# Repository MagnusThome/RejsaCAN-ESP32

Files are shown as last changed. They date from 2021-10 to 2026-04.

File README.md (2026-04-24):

# RejsaCAN

RejsaCAN is a 3x5 centimetre small ESP32 or ESP32-S3 based board aimed at car use that I put together for my own use in my assorted crazy car projects. The board has an onboard CAN interface and can be powered directly from the car (5-24V). It also includes the option to auto shutdown so not to drain the car battery. This is especially important if you have it plugged in to a car OBD2 connector since these always supply constant 12V power to the connector, even when the car is parked and turned off.

There is no bespoke code for the board apart from pin definitions, it's just a piece of universal hardware, but by using easy to use open source Arduino libraries it can be made to interface not only to various CAN buses, Network/Wifi and Bluetooth but to numerous sensors and other peripherals using the ESP32's built in interfaces.

You can assemble your own board if you want, you find schematics, Gerber files and bill of materials in the <a href=Schematics>schematics folder</a>. I currently have a few extra boards so if you need one or more factory assembled boards you can always contact me at magnust@gmail.com.
  
### Nice review and get started guide at cnx-software  
  
https://www.cnx-software.com/2023/05/12/rejsacan-esp32-s3-can-bus-board-arduino-car-hacking/  
  
### Navigate  
  
- <a href=./>Main page (this page)</a>  
 
- <a href=Projects%20and%20ideas>Fun projects and ideas</a>  
 
- <a href=Schematics>Schematics</a>

- <a href=Code%20Examples>Code examples</a>
 
- <a href=Tips%20to%20setup%20IDE%20and%20get%20started>Links to some different CAN libraries and tips to get started</a>  
  
-  <a href=3dprint>Examples of 3D printable housings</a>  

-  <a href=Auxiliary%20boards>Some odd auxiliary boards I made to mount an OBD2 connector, display, thermal cam...</a>  

<hr>
  


## Pinout  
  
See complete pinout.h https://github.com/MagnusThome/RejsaCAN-ESP32/blob/main/Schematics/

S3 rear

## Schematics

click to get full schematics



## The board is based around an ESP32 or ESP32-S3 chip

The ESP32-S3 is a very nice and capable chip that supports a mind boggling range of different communication standards and hardware auxiliaries making it a very versatile "hub" for shuffling data between different systems.  

- SPI bus
- I2C bus
- BLE (Bluetooth 5)
- Wifi (both as AP or client)
- Networking, everything from simple http, mqtt, ajax, ntp to running a full webserver on it with a user interface
- USB port (serial in/out and also OTG as virtual keyboard, wireless storage...)
- Analog input, PWM or analog output

## Examples

- Read CAN data and send back CAN packets to control the car (set to sport mode as default, lock doors when driving away, this is one of my current projects)
- CAN to BLE or network/Wifi bridge
- CAN interface for sniffing CAN bus with for example SavvyCAN
- Read I2C/SPI/analog sensor data and write to CAN bus for CAN bus based data loggers
- Publish live telemetric data on internet from Racechrono (I'm starting this project now)
- Drive alarm beeper or LED to show status of CAN data (like my small project Money Shift Saver and also low oil pressure warning)
- Drive high power peripherals using a driver board
- Translate CAN data between two CAN buses (like my small project Current Gear HUD here on github)

- I have already made a connector board to attach the RejsaCAN on the back of the commonly available small ILI9341 touch screen.

## Ideas for peripherals



- IR camera sensor arrays (MLX90xxx or AMG8833) to log tire, brake, drivetrain temperatures over BLE to Racechrono or CAN based loggers (like my project RejsaRubberTrac https://github.com/MagnusThome/RejsaRubberTrac)  
- Laser based TOF distance sensor to log suspension travel (I did this too with RejsaRubberTrac)  
- SPI or I2C based color displays to show CAN bus data like IC intake or oil temps or alarms  
- SPI or I2C based color displays to show live telemetric data fetched over BLE from Racechrono  
- A second CAN port  
- Driver board to drive high power items  
- Step motor drivers  
- Multiple input analog or digital boards  
   
## One of the 3D printed housings with OBD2 connector I've made


## Or just the board and screw terminals


# CAN interface

You can hook the board up straight to the car's OBD2 port or attach it directly to any CAN bus. You just need to connect the four wires. 12V power, ground, CAN high and low. There is of course a bus termination resistor on the board, it can be disabled if not needed by cutting a pcb trace and optionally mounting a pin header and jumper.

# Functionality

The idea was to make an as small as possible CAN + ESP32 board with as many cool and useful "good to have" functions as possible included. You know as well as I do that when tinkering around you suddenly get a new idea and need x or y :-D 

## Auto shutdown

When the engine is running and charging the car battery the incoming voltage used to power the board is a little bit higher than when the engine is stopped. This can be used to automate board shutdown so not to drain the car battery. As default the on board DC-DC power circuit will shutdown the whole board when the power voltage is below the "engine is running" threshold and boot up the board when it is above. But you can run the board in a number of other ways too, for example using ESP32 sleep mode, waking it and putting it to sleep depending on CAN traffic, voltage level from the car, delays and so on.

- An output (FORCE_ON GPIO17) can be pulled high to keep the board running even if the car voltage drops below the threshold (instead of disabling the auto shutdown fully on the pcb by shorting the "ALWAYS ON" bridge). The ESP32 can keep this pin high even during sleep.

- A digital input (SENSE_V_DIG GPIO08) monitors if the car voltage is above or below the "engine running" threshold. This can both be used to trigger waking the board from sleep or just as a simple check if the engine is charging the car battery or not.  

- The voltage from the car can be monitored using analog input (SENSE_V_ANA GPIO9) to check not only charging level but also battery discharge level when parked, health of charging, health of battery, detect large loads being switched on or off in the car and so on.

- The CAN data input (CAN_RX GPIO13) can also be used to trigger waking up the board from sleep as soon as CAN traffic is detected.

Either one can just let the board turn on and off with the auto shutdown hardware circuitry straight out of the box or you can run it in combination with software. For example, when the car voltage rises and the board boots you can pull FORCE_ON high to make sure the board keeps running even if there is a drop of voltage, for example due to red light start/stop functionality in the car or modern cars turning down battery charging even when driving. Then you just monitor either the threshold with SENSE_V_DIG or set your own thresholds using SENSE_V_ANA and then add your own timer delays or whatever. And of course, you can use CAN to check if the car is stopped in a multitude of ways, rpm, speed, gear...

### Fine tuning on/off voltage thresholds  

If your car has a more modern battery type than the old acid/led type or if it does the battery charging slightly different you might want to adjust the on/off voltage thresholds. If you keep R5 as 33k and adjust R4 you can get these switch-on and -off voltages:

| **R4** | **Turn on at** | **Turn off at** |
|---:|---:|---:|
| 91k | 13,7V | 13,0V |
| 90k | 13,6V | 12,9V |
| 89k | 13,5V | 12,8V |
| 88k | 13,4V | 12,7V |
| 87k | 14,3V | 12,6V |
| 86k | 13,2V | 12,5V |
| 85k | 13,1V | 12,4V |

### 24V vehicles

For 24V vehicles you can change the on/off voltage threshold by soldering on a resistor at the empty "ADJUST" position. I don't know what voltages one can expect in these vehicles while charging and not charging the battery so I have no idea what an appropriate resistor value should be there. 

matrix power scenarios  

## "Good to haves"

### Three on board LEDs  

- Green power LED that shows if the board is turned on or not. If using the auto shutdown the green LED (and the board) will be turned on and off depending on if the car voltage is over or under the auto start/shutdown threshold.

- Blue LED to use for anything you fancy (BLUE_LED GPIO10) (this one is red on some boards due to the blue led being out of stock lately)
- Yellow LED to use for anything (YELLOW_LED GPIO11)

### Extra UART RX/TX

The ESP32-S3 has a built in USB port for uploading firmware, OTG support(!) and general communication. But on the board's rear there are breakout pads for a second UART (TXD0 and RXD0) so you can use this as a serial port and the board's USB port for other tasks like JTAG or OTG, acting as a peripheral keyboard, mouse, wireless storage and so on.

### 3V3 HIGH DRIVER

The GPIO pins on the ESP32-S3 can, in addition to general digital circuitry, also drive 10-20mA loads like LEDs and other smaller loads. But on the RejsaCAN board there is an added more powerful driver circuit that can drive slightly larger loads of a few hundred mA at 3,3V. This can be used for different things like powering external sensors or a small display that you want to be able to shutdown fully to minimize power consumption while in sleep mode for example. This 3V3_SWITCHED output is controlled by HI_DRIVER (GPIO21). The ESP32-S3 can keep this on or off when in sleep mode.

There is also a 3,3V power output pad in the row of connection pads on the board that is turned on whenever the board is running. Keep in mind that this is _not_ a 3V3 input to drive the board, it is only an output to drive external I2C, SPI and other sensors.

### SD card reader

The ESP32-S3 has an SD micro card reader on the rear of the pcb. It is connected to SPI and select SD_CARD (GPIO45)

### Other general IO pins
  
All the GPIOs found on the row of connector pads are general purpose. They can be PWM, analog, digital in/out whatever, special protocols driving or reading most things you can think of. But for ease of use for me with occasional lousy memory I have marked some default uses:  
  
I2C SDA  (GPIO1)  (A0)  
I2C SCL  (GPIO2)  (A1)  
GND  
3V3  
  
SPI MISO / MTDI  (GPIO41)  
SPI CLK  / MTCK  (GPIO39)  
SPI MOSI / MTDO  (GPIO40)  
  
General  (GPIO12)  
General  (GPIO48)  
General  (GPIO47)  
High driver switched output max 500mA  (GPIO21)  

On the rear side of the pcb you can get to a few extra pins but it's not possible to solder pin headers here due to the esp-module being on the other side of the board where these pads are.  
  
General  (GPIO6)  (A5)  
General  (GPIO7)  (A6)  
General  (GPIO15)  
General  (GPIO16)  
MTMS  (GPIO42)  
PROG  (GPIO0)  
JTAG_ENABLE  (GPIO3)  
TXD0   
RXD0  

### CAN bus

As mentioned earlier the CAN_RX (GPIO13) can wake the ESP32-S3 from sleep whenever any traffic is seen on the CAN bus.

To minimize power draw when not using the CAN bus, for example not listening to the bus to detect traffic to wake the ESP32 from sleep mode, the CAN transceiver can be put in standby mode by pulling CAN_RS (GPIO38) high. The ESP32-S3 can keep this pin high even when in sleep mode reducing the complete boards power draw to an absolute minimum.

The rise time of the CAN transceiver chip can be changed pulling CAN_RS (GPIO38) low. Default is keeping the pin unmodified in high impedance state for an optimal not-to-fast rise time setting. See specs for the transceiver chip SN65HVD230DR.

### JTAG

You can either run JTAG over the USB port or optionally keep the USB port free by connecting your JTAG hardware to MTDI, MTDO, MTCK and MTMS on the board. Note that MTMS is only available on the board's rear. The other are available in the row of connecting pads. Incidentally the MTDI, MTDO and MTCK are the same as the SPI default pins.

To enable JTAG mode you need to pull the JTAG_ENABLE pad, found on the rear of the board, high or low at boot.

### Board version

On v3.x boards you can programmatically check what version of the board your code is running on and adjust accordingly for the small changes that have been made on the boards. Set GPIO4 and GPIO5 to input pullup and check if the inputs are high or low.

- v3.1 = GPIO4 low and GPIO5 high  
- v3.2 = GPIO4 high and GPIO5 low  

### Changes

#### from v3.1 to v3.2

- Added RS control of the CAN chip to set both standby mode and faster rise times
- Added better over voltage protection on power from the car
- Upgraded over voltage protection on USB power
- Enabling ALWAYS_ON is now done by shorting two clearly marked pads on the rear of the board
- An added empty spot for resistor R19 ADJUST which can be added to lower the start/stop voltage threshold for the board
- For panic situations when you need more pins ;-) the GPIO6, GPIO7, GPIO15 and GPIO16 are available as unmarked pads but only on the rear of the board
  
#### From v2.3 to v.2.4
  
- Upgraded over voltage protection on USB power  

#### From v2.4 to v.2.5 and 3.2 to 3.3
  
- DC-DC converter supports 24V input. The auto switch on/off threshold can be changed by changing two resistor values.  

## Power consumption  
 
At 14V the complete board draws *on average* roughly:  
- Bluetooth turned on but no connections = 16mA (+ 4mA for power LED)
- Wifi turned on as AP with local web server but no connections = 46mA (+ 4mA for power LED)
- No wifi or Bluetooth = 14mA (+ 4mA for power LED)
- Sleep = 3mA (+ 4mA for power LED). Note that the CAN transceiver is fully active and the DC-DC buck converter probably has some idle draw also.
- Sleep and CAN transceiver put in standby = hmmm, must test this, a fraction of a mA is my guess.
   
## Housing

Check out 3D printable housings in the <a href=3dprint>the 3D-print directory</a>. So far I've made one housing where you connect using a cable and another one with an integrated OBD2 connector to plug directly into the car.



transparent-case-1

small-housing(0)
  


## Connecting the board

When not using the housing with an integrated OBD2 connector or the screw terminals as seen in the picture above I've used a widely available OBD2 splitter cable (flat cable) that has one male and two female connectors. I hook up the male connector to the car, cut off one female connector and wire the remaining pig tail cable into the RejsaCAN board and one female connector is then free for other equipment to hook up to the car.

Picture showing what wires to use but please measure your cable and don't trust all these splitter cables to be 100% identical. (the second female splitter connector is not visible in pic)
   
OBD2 splitter pinout
 
small-housing(3)
 
small-housing(2)

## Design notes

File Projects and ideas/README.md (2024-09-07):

# Projects ideas and tips

I add fun stuff on this page from time to time... 
  
A superb list of resources: https://github.com/iDoka/awesome-canbus  
  
# Alarm

A beeper that only takes a few milliamperes is driven directly from one of the ESP32 pins. Alarm set on over rev in this case but can of course be oil and/or water temperatures, oil pressure (if you know the PID) or anything you want.



# CAN data on a touch screen

Just a first test of CAN info on the screen with ugly fonts ;-)  The wiring between the boards will be replaced by a super small interconnect board so the RejsaCAN is sandwich mounted behind the display board. This display board also has an SD card reader slot that you can use for logging data.

Touch-screen(1)



# SLCAN / CANUSB
  
  Alexander Cus ported the SLCAN by mintynet www.github.com/mintynet/esp32-slcan to TWAI so it works with RejsaCAN ESP32-S3:
    
  www.github.com/Pacerino/TWAI_SLCAN  
    
  Here's a lot of info on SLCAN / USBCAN in a PDF: www.can232.com/docs/canusb_manual.pdf

# Collect telemetry data from Racechrono live and export to display, internet or whatever
  
An example how to use the "Monitor" API in Racechrono to get a live feed of any of all data Racechrono holds using a RejsaCAN board running on car's 12V (or any board based on an ESP32 or NRF52 MCU run on 5V) to get a live feed of data from Racechrono over BLE/Bluetooth. This example code is made for a commonly available ILI9341 based display simply connected via SPI. More info and code here https://github.com/MagnusThome/Racechrono-LIVE-telemetry-data-export

www.youtube.com/watch?v=f61Pw1ZjPyw  
  
  
# Collect car (or other) data and transmit to Racechrono for logging 

https://github.com/timurrrr/arduino-RaceChrono

# Wican ported to also support RejsaCAN  
The very comprehensive Wican project has been ported by Pawel to also support RejsaCAN boards!  

https://github.com/pawelka/wican-fw  
  
# CAN log all to Serial over USB and Bluetooth

I'm using Techstream (the software the garage uses to check up on the car) to ask for different non standard OBD2 data over the OBD2 port (steering angle, oil pressure, brake pressure...) and simultaneously log all the traffic with this RejsaCAN in the picture below, logging both the requests from Techstream and the replies from the car. Simple <a href=https://github.com/MagnusThome/RejsaCAN-ESP32/blob/main/Code%20Examples/>Arduino code for this is in the examples directory</a>. I can either save all data over USB to my PC or save to a log file on my mobile phone over Bluetooth using for example this app https://play.google.com/store/apps/details?id=de.kai_morich.serial_bluetooth_terminal&hl=en&gl=US



# Using RejsaCAN as a sniffer interface with CAN software tools

** Support for ESP32-S3 here https://github.com/MagnusThome/ESP32S3RET **

I installed ESP32RET on the board and hooked it up to the CAN software tool SavvyCAN on my PC

At https://github.com/collin80/ESP32RET you get the code to put on the ESP32 so it runs as a hardware interface between the car and SavvyCAN on the PC. You can run it over USB, Bluetooth or Wifi. 

www.savvycan.com

## ESP32RET menu
  
Menu on serial port over USB to set up ESP32RET on the ESP32:

```
Config Commands (enter command=newvalue). Current values shown in parenthesis:

SYSTYPE=1 - Set board type (0 = Macchina A0, 1 = EVTV ESP32 Board
LOGLEVEL=1 - set log level (0=debug, 1=info, 2=warn, 3=error, 4=off)

CAN0EN=1 - Enable/Disable CAN0 (0 = Disable, 1 = Enable)
CAN0SPEED=500000 - Set speed of CAN0 in baud (125000, 250000, etc)
CAN0LISTENONLY=0 - Enable/Disable Listen Only Mode (0 = Dis, 1 = En)

CAN1EN=1 - Enable/Disable CAN0 (0 = Disable, 1 = Enable)
CAN1SPEED=500000 - Set speed of CAN0 in baud (125000, 250000, etc)
CAN1LISTENONLY=0 - Enable/Disable Listen Only Mode (0 = Dis, 1 = En)

CAN0SEND=ID,LEN,<BYTES SEPARATED BY COMMAS> - Ex: CAN0SEND=0x200,4,1,2,3,4
CAN1SEND=ID,LEN,<BYTES SEPARATED BY COMMAS> - Ex: CAN1SEND=0x200,4,1,2,3,4
MARK=<Description of what you are doing> - Set a mark in the log file about what you are about to do.

BINSERIAL=0 - Enable/Disable Binary Sending of CANBus Frames to Serial (0=Dis, 1=En)

BTMODE=0 - Set mode for Bluetooth (0 = Off, 1 = On)
BTNAME=ELM327-ESP32RET - Set advertised Bluetooth name

LAWICEL=1 - Set whether to accept LAWICEL commands (0 = Off, 1 = On)

WIFIMODE=2 - Set mode for WiFi (0 = Wifi Off, 1 = Connect to AP, 2 = Create AP
SSID=ESP32RETSSID - Set SSID to either connect to or create
WPA2KEY=aBigSecret - Either passphrase or actual key

```

Good videos to get started:

https://youtu.be/kdA5Gdf3FAk

https://youtu.be/GOuglqFtmOE





# Infrared camera to monitor tire temperatures on track
  
Since it runs on 12V why not make an infrared camera to measure and log your cars tire temperatures for a couple of tenners per wheel. Works with both Racechrono and Harry's Laptimer. Downloadable code and lots of info here: https://github.com/MagnusThome/RejsaRubberTrac

  
  
# ISOTP BLE Bridge  
  
Works for example with SimosTools, an android based ecu flashing and logging software  
  
https://github.com/bri3d/esp32-isotp-ble-bridge  
https://github.com/Switchleg1/esp32-isotp-ble-bridge (fork)  
  
# Reverse OBD2
  
This one acts like a fake car replying to OBD2 requests. The code running on it changes the rpm and other data in sequence.  

https://github.com/MagnusThome/ESP32_OBD2_Emulator  
  
reversed OBD2

# A cool web based OBD2 project by "EQMOD"  

https://github.com/EQMOD/REJSACAN_OBDWEB
  
290242772-40da870d-5916-4593-a670-4dd24b201a21  
  
290242815-92e0deb7-28c5-4523-9fd6-6baa8f7f16f6  
   
 <hr>

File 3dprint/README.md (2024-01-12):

# RejsaCAN v3.x ESP32-S3

Three housings done so far:

<hr>
  
  
- Very thin very small and minimalist with wire going directly into the casing
<br clear=all>
<hr>
  
  

- Standard with integrated OBD2 connector. 
  
<br clear=all>
<hr>

  

- Sandwich mounted board with integrated OBD2 connector. Flatter, doesn't stick out as long from the jack as the standard version but is wider so will not fit in all cars.  
  
<br clear=all>
<hr>

## Standard
  

  
M2 screws and inserts  
  
 





## Sandwich mounted board
 


## Add a beeper?  
 


# Minimalist small and flat

small-housing(1)

small-housing(3)

small-housing(2)


  
# RejsaCAN v6.0 dual CAN with ESP32-C6  

RejsaCAN v6 0  

comparison  

sandwich interconnect board
  
screw terminal 1  
  
screw terminal 2  
  
screw terminal 3  
  
screw terminal 4

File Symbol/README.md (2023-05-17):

# ESP32-3S-CAN Symbol Library

A Smbol Library (made with [KiCad](https://www.kicad.org/) but easy to import into for example [EasyEDA](https://docs.easyeda.com/en/Import/Import-KiCAD/index.html)) to make it easier for others to integrate the ESP32-3S-CAN into their own project

238754253-4974dff2-95a3-413c-ab60-1d5ed4ff27b9

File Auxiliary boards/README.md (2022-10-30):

# Some extras I made...

## OBD2 connector boards
  
To avoid using short cables I made two different interconnect boards. One for sandwich mounting and one 90 degree mounted.
  
### Angled 90 degrees:
  
  
  
### Sandwich mounted:  
  
    

## Micro SD card reader for v2.x (non S3) boards
  
   
  
## Display connector boards  
  
So you get the correct pinout for some small SPI display boards with touch.   
  
  

## Thermal camera board  
  
See https://github.com/MagnusThome/RejsaRubberTrac  



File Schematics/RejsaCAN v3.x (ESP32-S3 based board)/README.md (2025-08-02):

# RejsaCAN v3.x (ESP32-S3 based board)
  
 
 


Alternative sandwich mounted OBD2 connector board
  
 
 


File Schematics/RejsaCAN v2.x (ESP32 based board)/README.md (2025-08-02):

# RejsaCAN v2.x (ESP32 based board)


  
 





Alternative housing  
  


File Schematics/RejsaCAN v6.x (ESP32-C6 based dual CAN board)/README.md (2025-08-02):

# RejsaCAN v6.x dual CAN  (ESP32-C6 based board)

sandwich interconnect board
  
screw terminal 1  
  
screw terminal 2  
  
screw terminal 3  
  
screw terminal 4 

Comparison of size - RejsaCAN v3.x single CAN vs RejsaCAN v6.x dual CAN 

comparison  

RejsaCAN v6 0

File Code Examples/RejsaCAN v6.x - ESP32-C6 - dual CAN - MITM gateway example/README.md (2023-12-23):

# Example how to use both two CAN bus ports on an ESP32-C6
  
- Everything that comes in on CAN0 is forwarded to CAN1. And vice versa
- Example in which you can add "Man In The Middle" MITM code to filter, convert, translate or swap data around
  
## ESP-IDF Toolchain
You need espressif's 5.2 toolchain or newer with the twai_v2 update which supports multiple CAN controllers. Today (dec 2023) the only way to do this is via ESP-IDF with for example VSCode. Not PlatformIO's built in espressif toolchain since it seems to be an older version (I might be wrong but I couldn't get it to compile with PIO's built in ESP-IDF, if you find out how please tell me :-)

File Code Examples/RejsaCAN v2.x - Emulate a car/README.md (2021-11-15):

# Emulate a car

This code replies as if it is a car with OBD2 

Any OBD2 standard PID requested gets a reply with a fake value. Default is single byte value replies only. Any replies that should be two or more bytes long can be added, the only ones currently added in the code are ENGINE_RPM and SUPPORTED PIDS.

A future logical addition to this code is adding analog potentiometers to MCU input pins and do analog to digital conversion to emulate data like speed, throttle position and so on. In theory this code can be expanded to make a vehicle without OBD2 to have a working OBD2 connector for a few basic data items.

Note the female instead of male connector:
reversed OBD2

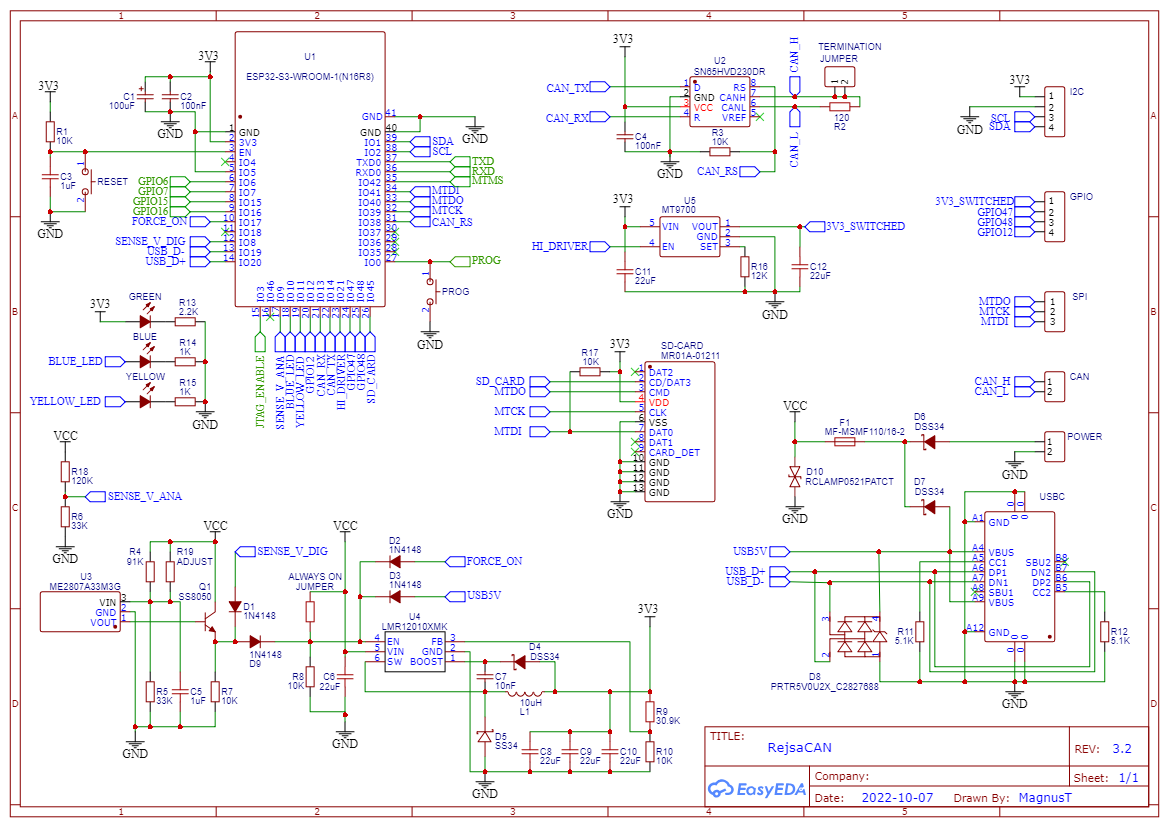
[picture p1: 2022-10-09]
Schematics/Schematic_RejsaCAN v3.2.png

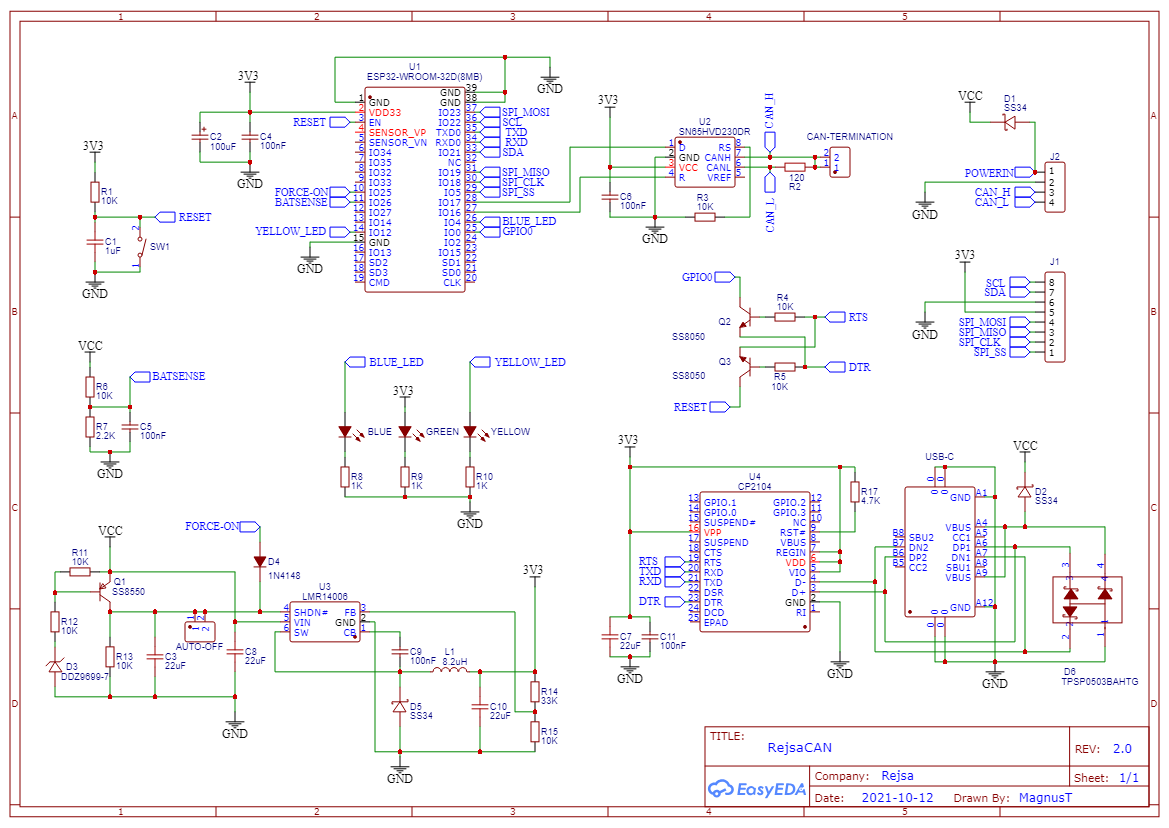
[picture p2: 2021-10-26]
Schematics/Schematic_RejsaCAN v2.0.png

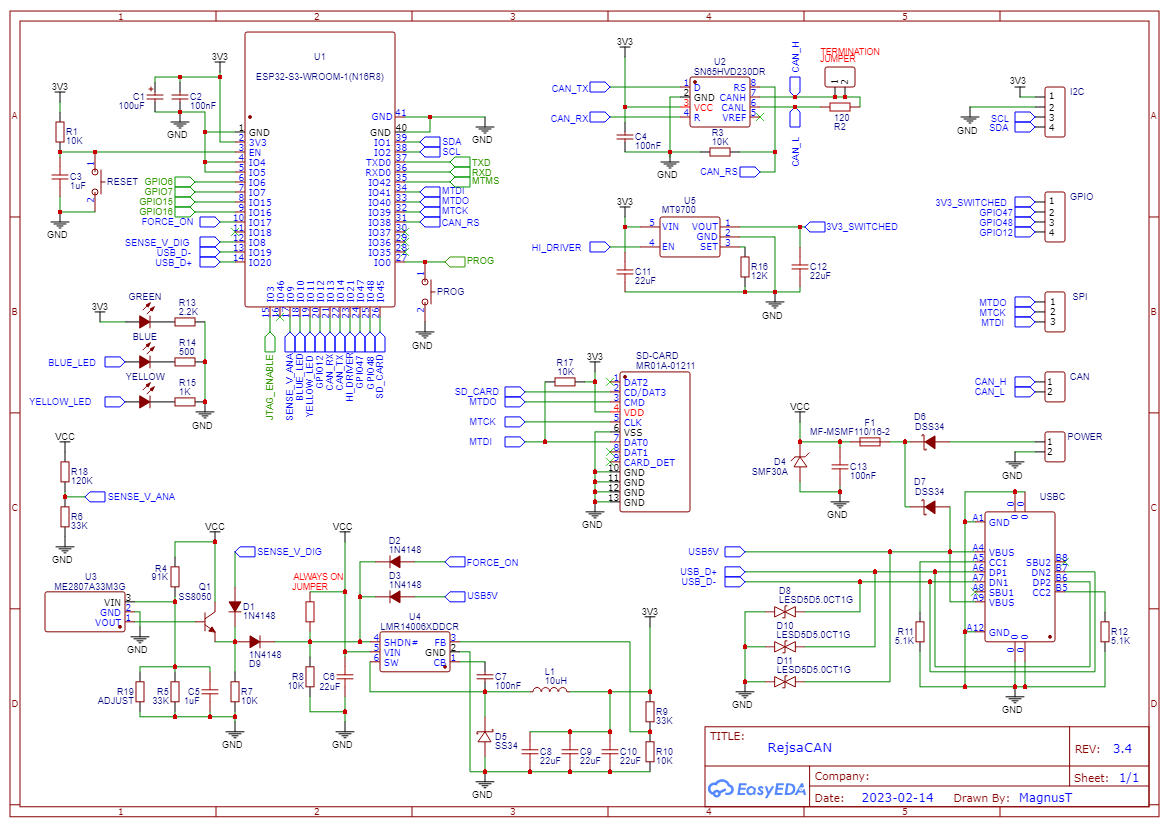
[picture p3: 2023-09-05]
Schematics/RejsaCAN v3.x (ESP32-S3 based board)/RejsaCAN v3.4 - Schematic.png

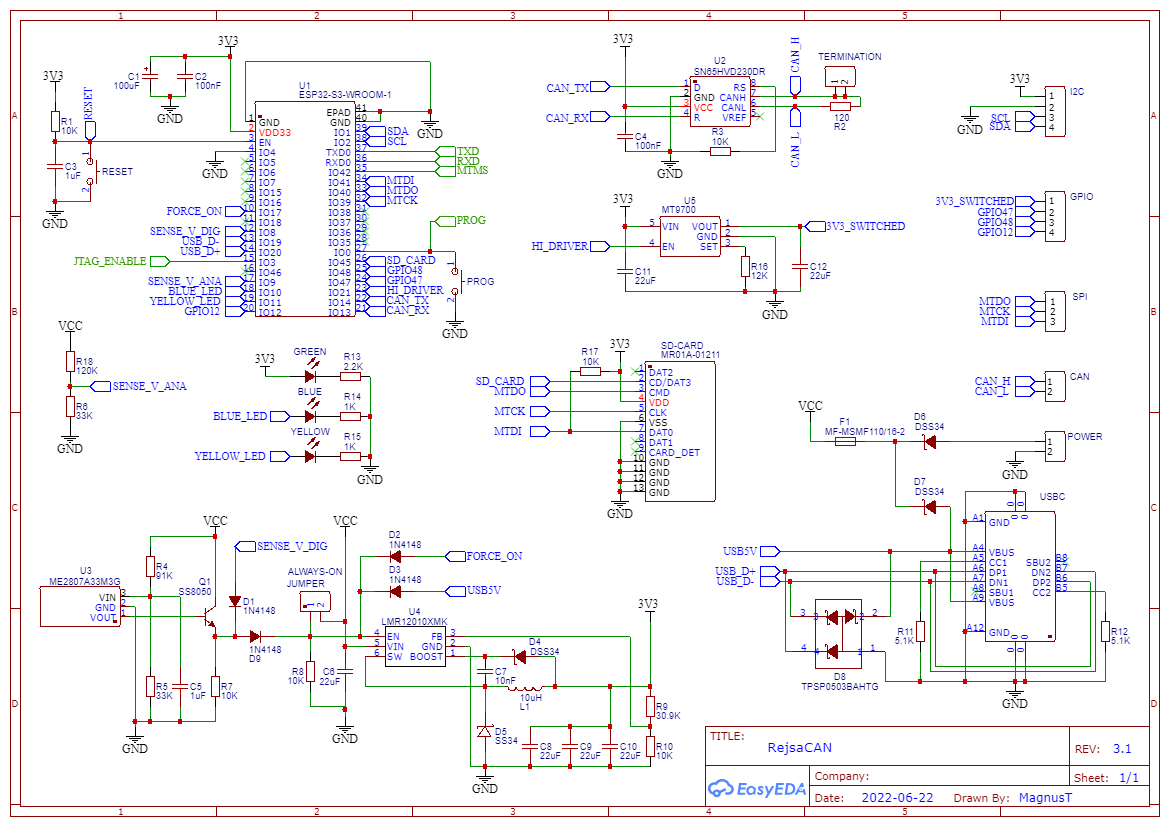
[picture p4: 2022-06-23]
Schematics/Schematic_RejsaCAN v3.1.png

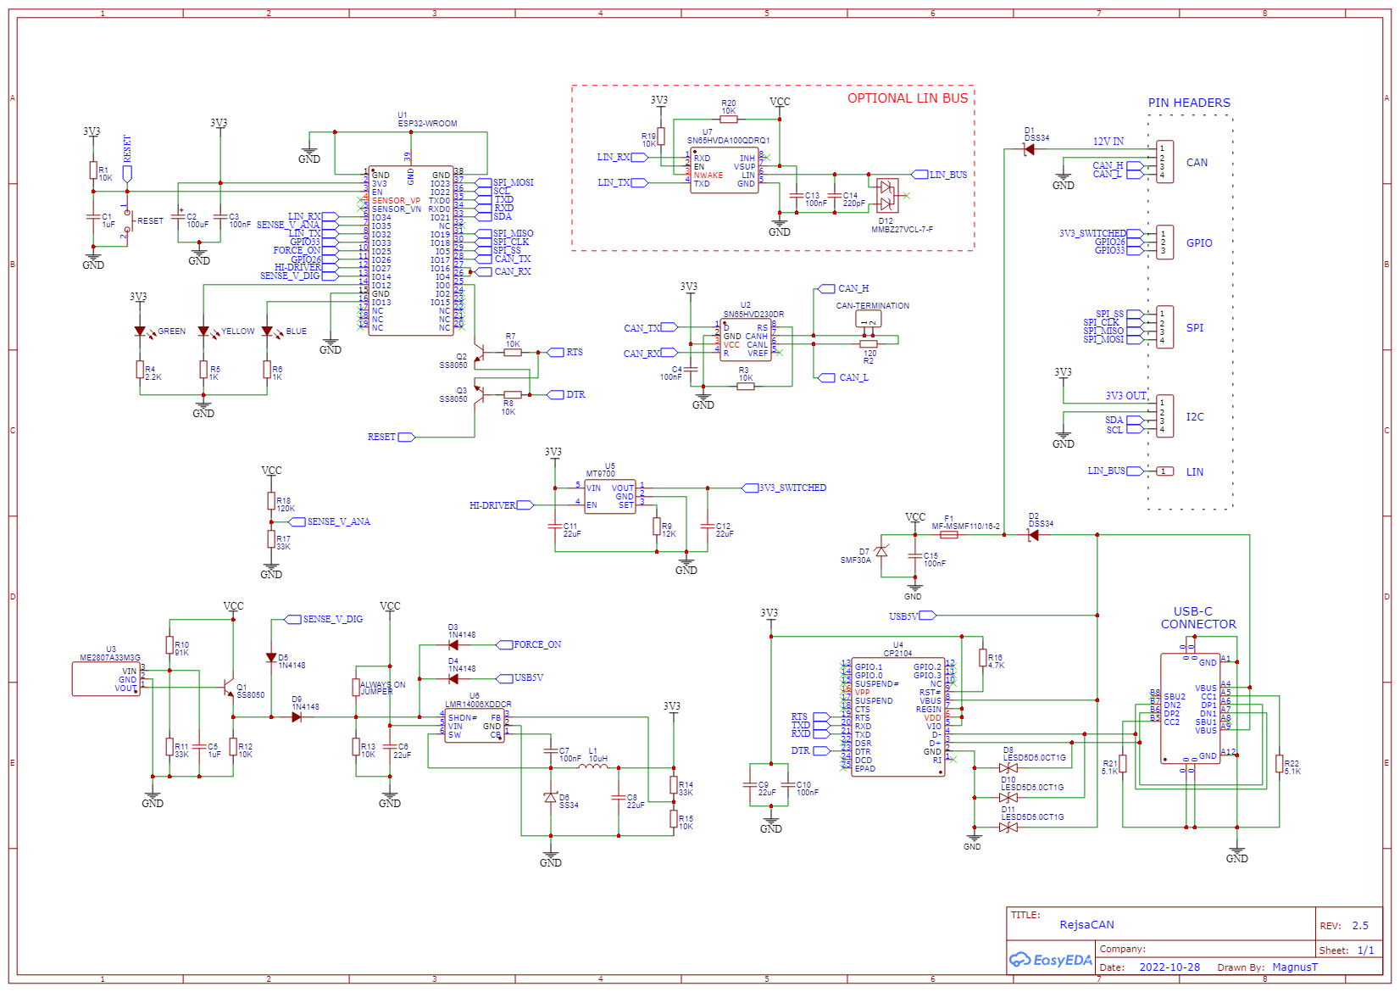
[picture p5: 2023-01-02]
Schematics/RejsaCAN v2.x (ESP32 based board)/RejsaCAN v2.5 - Schematic.png

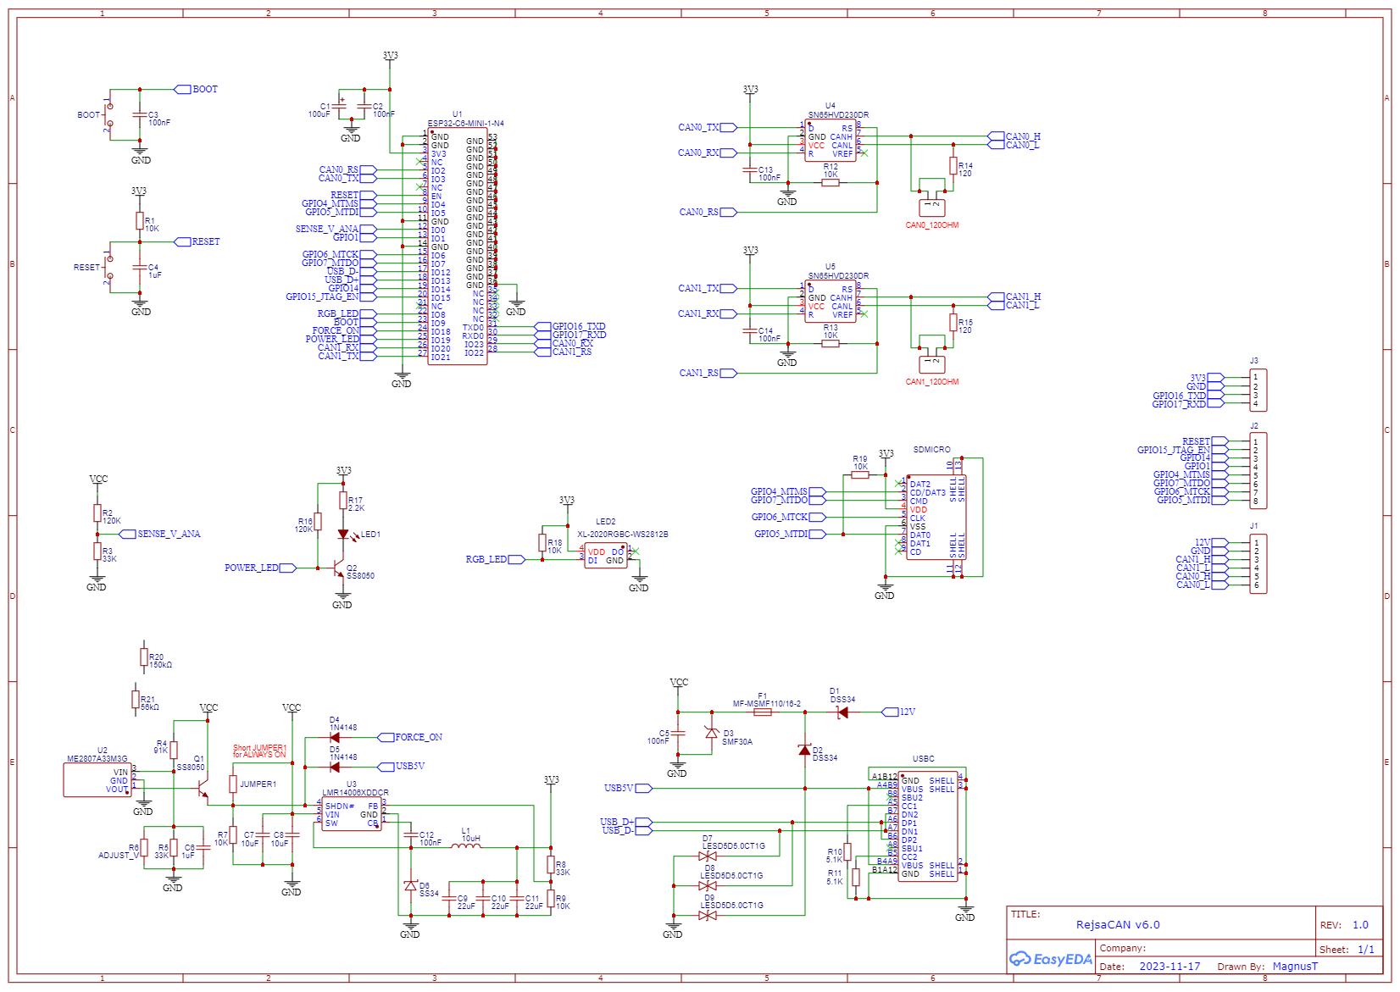
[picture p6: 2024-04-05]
Schematics/RejsaCAN v6.x (ESP32-C6 based dual CAN board)/RejsaCAN v6.0 - Schematic.png

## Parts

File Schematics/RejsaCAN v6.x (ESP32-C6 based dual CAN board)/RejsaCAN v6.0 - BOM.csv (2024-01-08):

ID | Name | Designator | Footprint | Quantity | Manufacturer Part | Manufacturer | Supplier | Supplier Part | Price
1 | 10uF | C8,C7 | C0805 | 2 | CL21A106KBYQNNE | SAMSUNG(三星) | LCSC | C2932476 | 0.071
2 | MF-MSMF110/16-2 | F1 | F1812 | 1 | MF-MSMF110/16-2 | BOURNS | LCSC | C210834 | 0.038
3 | 22uF | C11,C9,C10 | C0603 | 3 | CL10A226MQ8NRNC | SAMSUNG | LCSC | C59461 | 0.008
4 | TF-115 | SDMICRO | TF-SMD_TF-115 | 1 | TF-115 | XUNPU(讯普) | LCSC | C266620 | 0.115
5 | ESP32-C6-MINI-1-N4 | U1 | WIFIM-SMD_ESP32-C3-MINI-1 | 1 | ESP32-C6-MINI-1-N4 | ESPRESSIF(乐鑫) | LCSC | C5736265 | 2.74
6 | 120 | R14,R15 | R1206 | 2 | RTT061200FTP | RALEC | LCSC | C159715 | 0.004
7 | 100nF | C2,C12,C13,C14,C3 | C0402_NEW | 5 | CL05B104KO5NNNC | SAMSUNG | LCSC | C1525 | 0.001
8 | 100uF | C1 | CASE-B_3528 | 1 | TAJB107K006RNJ | Kyocera AVX | LCSC | C16133 | 0.142
9 | DSS34 | D1,D2 | SOD-123_L2.8-W1.8-LS3.7-RD | 2 | DSS34 | STARSEA | LCSC | C84632 | 0.059
10 | SMF30A | D3 | SOD-123_L2.8-W1.8-LS3.7-RD | 1 | SMF30A | DOWO | LCSC | C366558 | 0.031
11 | XL-2020RGBC-WS2812B | LED2 | LED-SMD_4P-L2.0-W2.0-BR-1 | 1 | XL-2020RGBC-WS2812B | XINGLIGHT(成兴光) | LCSC | C5349955 | 0.08
12 | GT-TC029B-H025-L1N | BOOT,RESET | SW-SMD_L3.9-W2.9-P4.15-LS5.0 | 2 | GT-TC029B-H025-L1N | G-Switch | LCSC | C843669 | 0.06
13 | 1uF | C4,C6 | C0402 | 2 | CL05A105KA5NQNC | SAMSUNG | LCSC | C52923 | 0.004
14 | 10K | R1,R7,R9,R12,R13,R18,R19 | R0402 | 7 | 0402WGF1002TCE | UniOhm | LCSC | C25744 | 0.001
15 | ME2807A33M3G | U2 | SOT-23_L2.9-W1.3-P1.90-LS2.4-BR | 1 | ME2807A33M3G | Nanjing Micro One Elec | LCSC | C236755 | 0.065
16 | SS8050 | Q1,Q2 | SOT-23-3_L2.9-W1.3-P1.90-LS2.4-BR | 2 | SS8050 | CJ | LCSC | C2150 | 0.015
17 | 1N4148 | D5,D4 | SOD-323_L1.8-W1.3-LS2.5-RD | 2 | 1N4148WS T4 | CJ | LCSC | C2128 | 0.01
18 | 2.2K | R17 | R0402 | 1 | 0402WGF2201TCE | UniOhm | LCSC | C25879 | 0.001
19 | 19-217/GHC-YR1S2/3T | LED1 | LED0603-R-RD | 1 | 19-217/GHC-YR1S2/3T | EVERLIGHT | LCSC | C72043 | 0.027
20 | 120K | R16,R2 | R0402 | 2 | 0402WGF1203TCE | UniOhm | LCSC | C25750 | 0.001
21 | 100nF | C5 | C0402 | 1 | CL05B104KB54PNC | Samsung Electro-Mechanics | LCSC | C307331 | 0.007
22 | SS34 | D6 | DO-214AC_L4.3-W2.7-LS5.3-RD | 1 | SS34 | MDD | LCSC | C8678 | 0.023
23 | LESD5D5.0CT1G | D7,D8,D9 | SOD-523_L1.2-W0.8-LS1.6-BI | 3 | LESD5D5.0CT1G | Leshan Radio | LCSC | C383211 | 0.017
24 | 33K | R3,R5,R8 | R0402 | 3 | 0402WGF3302TCE | UniOhm | LCSC | C25779 | 0.001
25 | 5.1K | R10,R11 | R0402 | 2 | 0402WGF5101TCE | UniOhm | LCSC | C25905 | 0.001
26 | LMR14006XDDCR | U3 | TSOT-23-6_L2.9-W1.6-P0.95-LS2.8-BL | 1 | LMR14006XDDCR | Texas Instruments | LCSC | C478074 | 0.878
27 | SN65HVD230DR | U4,U5 | SOIC-8_L4.9-W3.9-P1.27-LS6.0-BL | 2 | SN65HVD230DR | TI | LCSC | C12084 | 0.749
28 | 91K | R4 | R0402 | 1 | 0402WGF9102TCE | UniOhm | LCSC | C4147 | 0.001
29 | 10uH | L1 | IND-SMD_L6.0-W6.0_SLP6028S | 1 | SLP6028S100MTT | Sunltech Tech | LCSC | C254862 | 0.256
30 | GT-USB-7010ASV | USBC | USB-C-SMD_G-SWITCH_GT-USB-7010ASV | 1 | GT-USB-7010ASV | G-Switch(品赞) | LCSC | C2988369 | 0.079

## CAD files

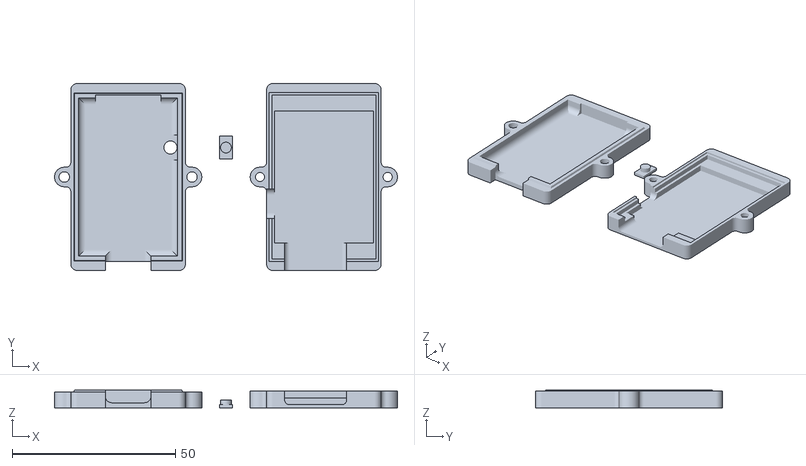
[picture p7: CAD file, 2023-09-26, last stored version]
3dprint/Small-flat-housing with SD card and Cable hole.stl
105.0 x 57.2 x 5.50

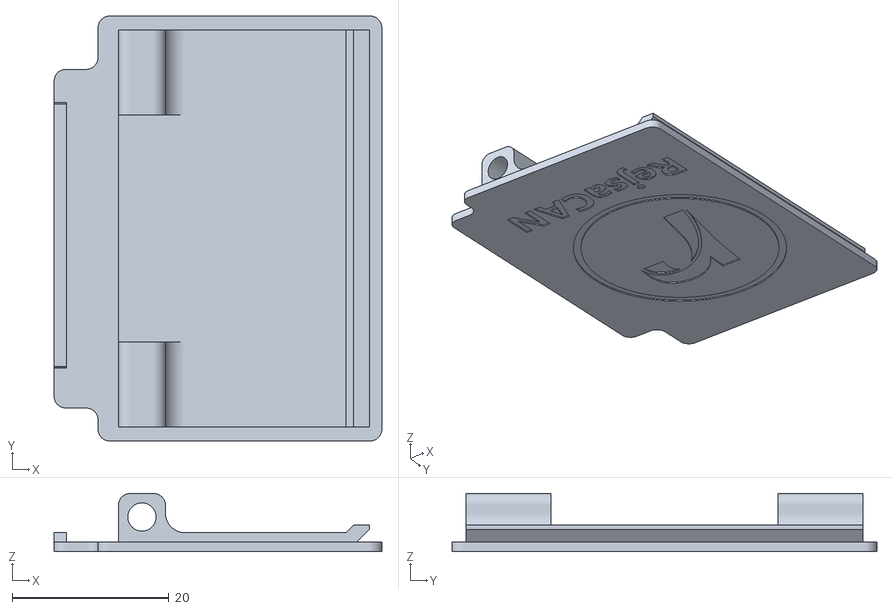
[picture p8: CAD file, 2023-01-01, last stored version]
3dprint/Horizontal-OBD2-connector-LID.stl
41.8 x 54.2 x 7.40

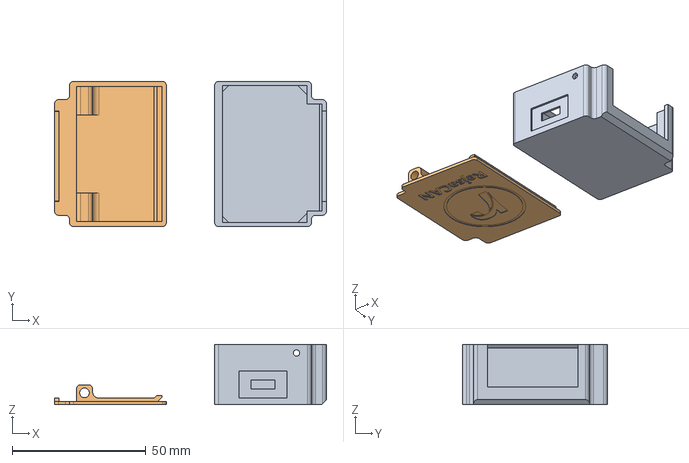
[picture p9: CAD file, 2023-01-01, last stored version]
3dprint/Horizontal-OBD2-connector.step
101.6 x 54.2 x 22.5 mm

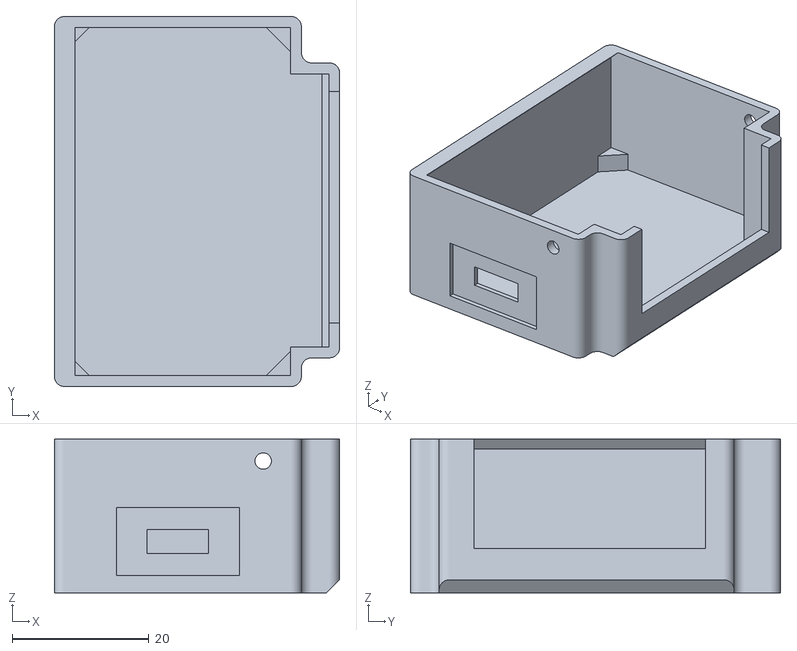
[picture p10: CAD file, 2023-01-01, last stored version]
3dprint/Horizontal-OBD2-connector-BASE.stl
41.8 x 54.2 x 22.5

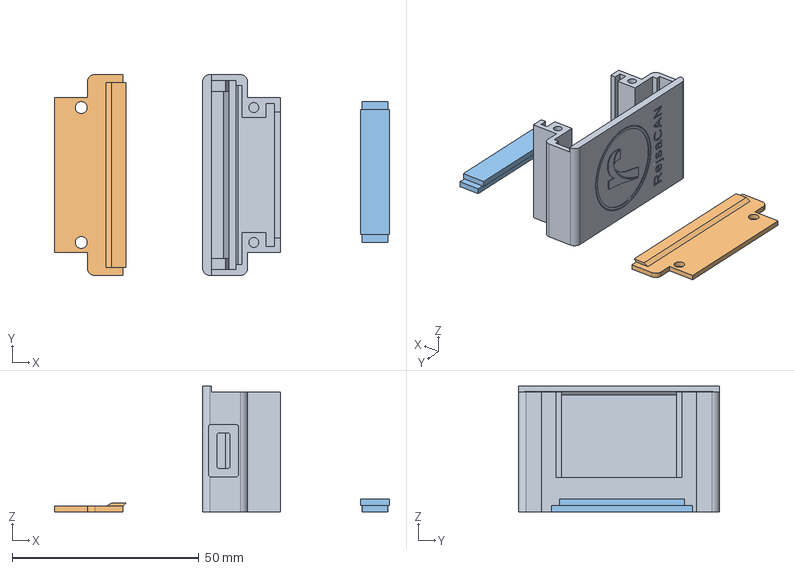
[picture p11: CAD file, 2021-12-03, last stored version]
3dprint/Vertical-OBD2-connector.step
89.7 x 53.8 x 33.6 mm

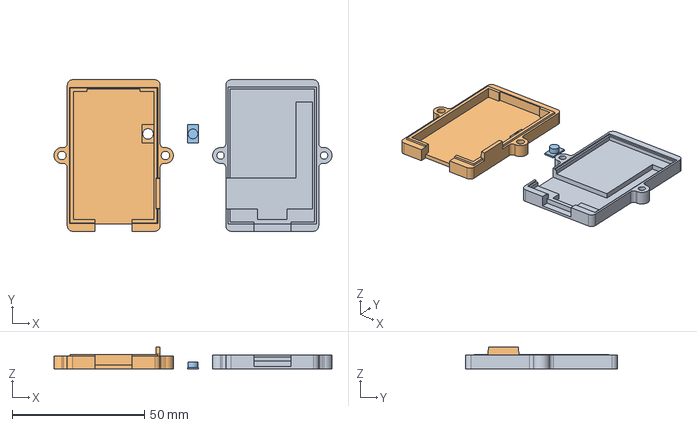
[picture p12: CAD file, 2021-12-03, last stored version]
3dprint/Small-flat-housing.step
105.0 x 57.2 x 8.30 mm

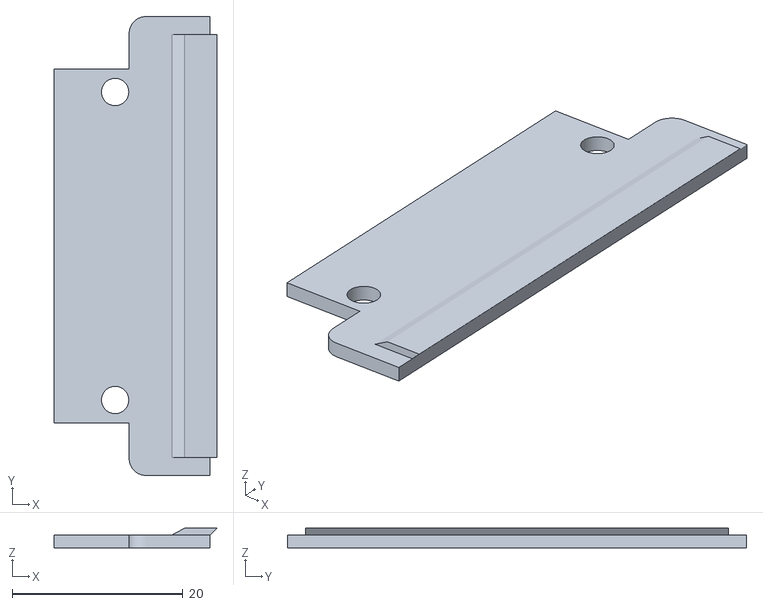
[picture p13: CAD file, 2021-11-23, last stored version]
3dprint/Vertical-OBD2-connector-LID.stl
19.1 x 53.8 x 2.30

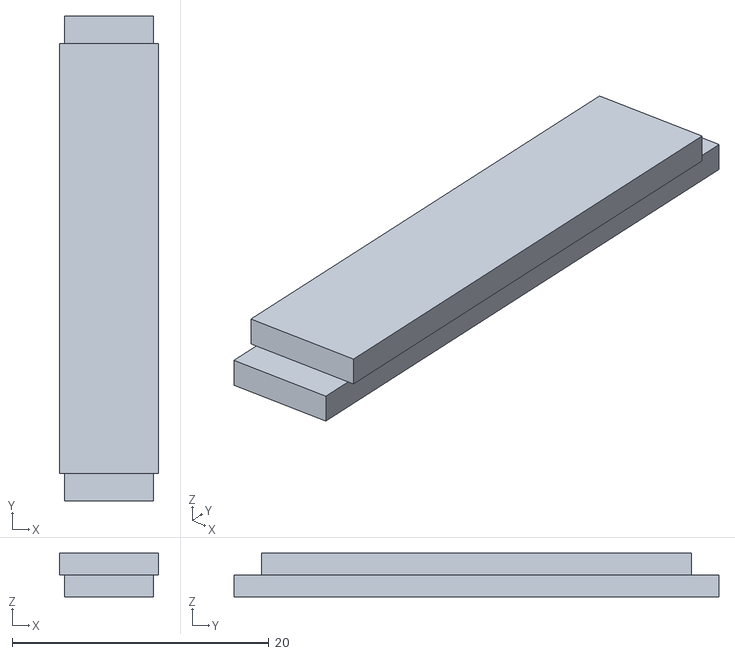
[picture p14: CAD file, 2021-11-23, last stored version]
3dprint/Vertical-OBD2-connector-small-lid.stl
7.70 x 37.8 x 3.40

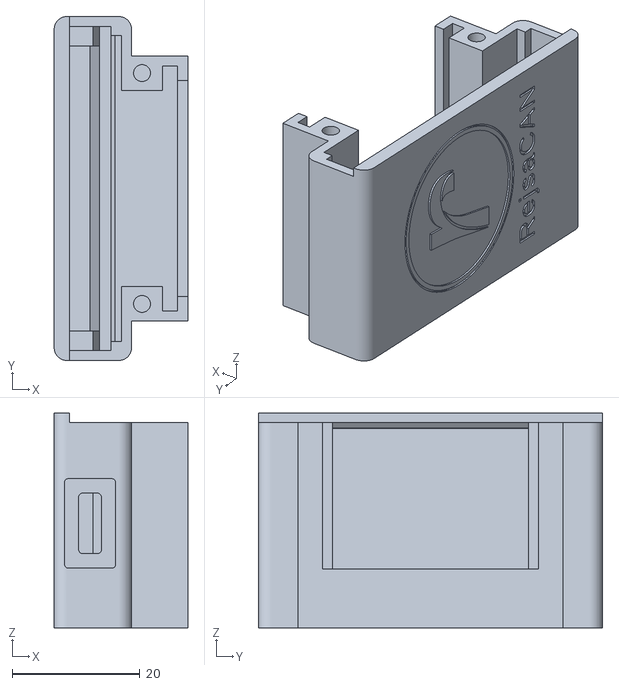
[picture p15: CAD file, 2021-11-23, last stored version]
3dprint/Vertical-OBD2-connector-BASE.stl
20.9 x 53.8 x 33.6

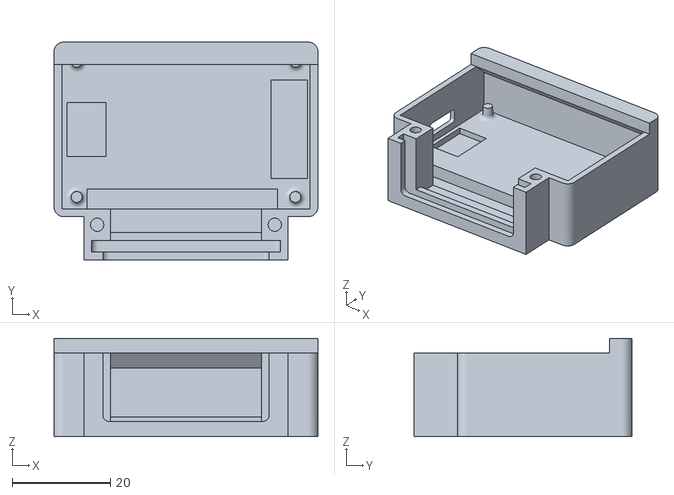
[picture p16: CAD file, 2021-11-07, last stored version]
3dprint/Housing-with-OBD2-connector-BASE.stl
53.6 x 44.3 x 20.0

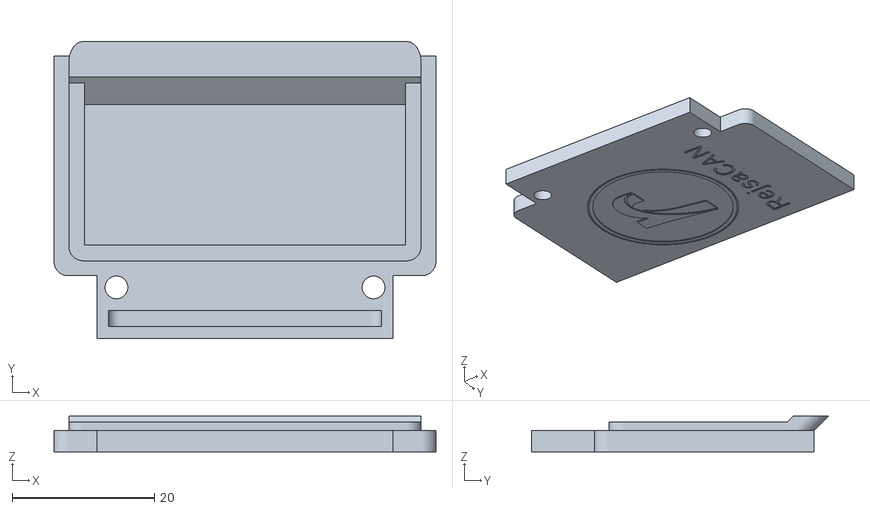
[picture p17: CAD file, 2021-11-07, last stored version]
3dprint/Housing-with-OBD2-connector-LID.stl
53.6 x 41.7 x 5.00

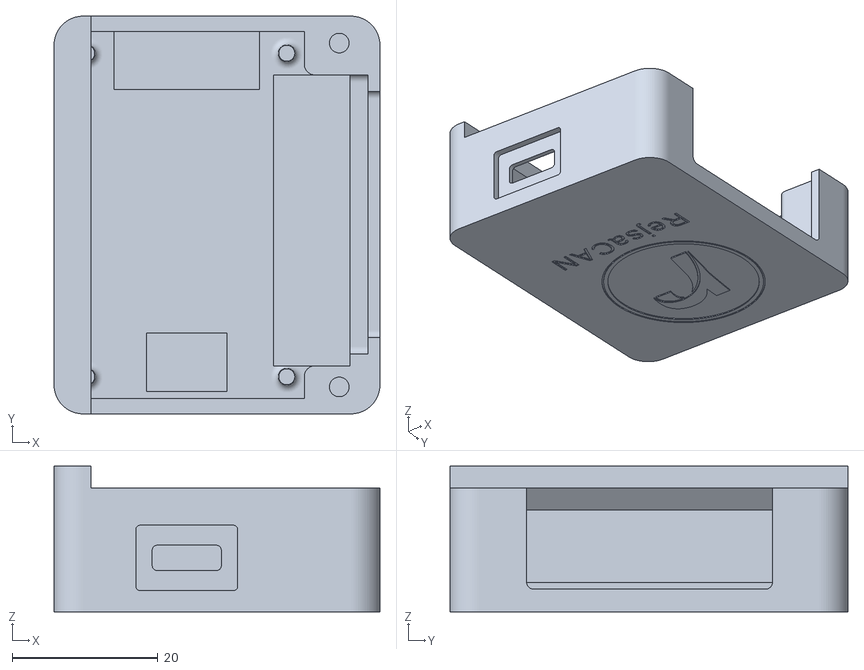
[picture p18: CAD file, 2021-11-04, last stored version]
3dprint/ODB2-connector-housing-BASE.stl
44.8 x 54.6 x 20.0

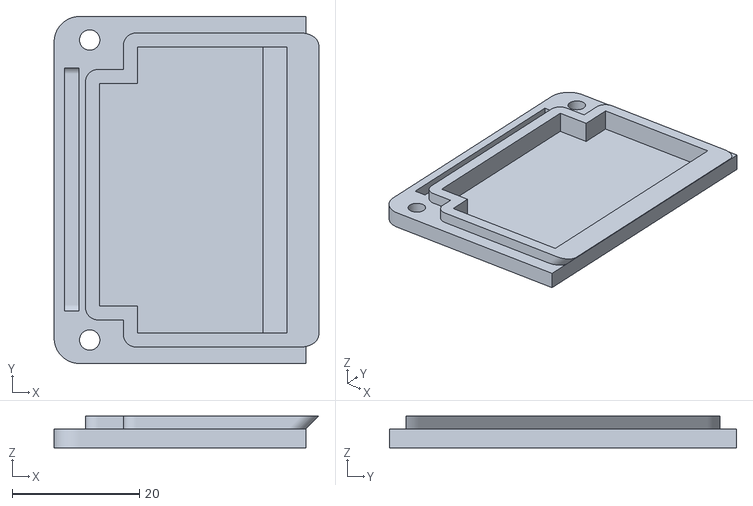
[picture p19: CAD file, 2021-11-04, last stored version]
3dprint/ODB2-connector-housing-LID.stl
41.7 x 54.6 x 5.00

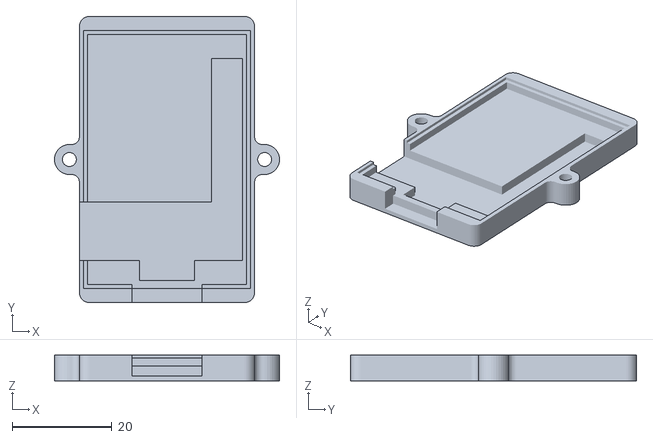
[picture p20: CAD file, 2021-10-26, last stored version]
3dprint/Small-flat-housing-BASE.stl
45.1 x 57.2 x 5.20

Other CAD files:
3dprint/Small-flat-housing-LID.stl
3dprint/Housing-Lid.stl
3dprint/Small-flat-housing with SD card and Screw terminal.stl

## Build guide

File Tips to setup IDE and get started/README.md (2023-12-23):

# What CAN library/libraries to use?

There are many CAN libraries that work with the ESP32, here are the ones I've found so far. If you are thinking about an ESP32 based CAN project my tip is to check out the examples included with each library, they will give you some idea on different approaches.

https://github.com/collin80/esp32_can  -  NOTE: This library now works with both ESP32 and ESP-S3
  
https://github.com/sandeepmistry/arduino-CAN

https://github.com/adafruit/arduino-CAN

https://github.com/timurrrr/arduino-CAN
  
If you only want to access OBD2 data and not dive into the lower layer CAN bus this is also available:

https://github.com/sandeepmistry/arduino-OBD2

I'm sure there are more libraries out there. If you find something that has some special advantage feel free to email me so I can add it here

# ESP32-S3, -C6 and other newer variants (TWAI)
  
Since the ESP32-S3 is slightly different when it comes to its CAN API compared to the older ESP32 one way to code for it is to use Visual Code Studio and the Espressif toolchain by following these install instructions:  
  
https://github.com/espressif/vscode-esp-idf-extension/blob/master/docs/tutorial/install.md  

I've made some examples that you can use in the Arduino IDE with just the libraries that come with the board installation if you don't want to use Visual Code Studio:  
  
https://github.com/MagnusThome/RejsaCAN-ESP32/tree/main/Code%20Examples (use the ESP32-S3 examples)  
    
But if you want to use the Arduino IDE and a known Arduino library this one is now supporting the S3: https://github.com/collin80/esp32_can  

I added a simplified OBD2 library for the above CAN library to make requesting standard OBD2 data really easy. It is a fork and rewrite of the OBD2 library written by sandeepmistry  
  
https://github.com/MagnusThome/esp32_obd2  
  
I also did a quick rewrite/hack of ESP32RET to support the newer ESP32-S3 chip (that does not have old school serial BT)  
  
https://github.com/MagnusThome/ESP32S3RET
  
You can also look into these interesting ports for ESP32-S3 that might be useful:  

https://github.com/pawelka/ESP32RET  
https://github.com/pawelka/esp32_can  
https://github.com/sdp8483/ESP32-Arduino-CAN   
https://github.com/Sheimy/TWAI_S3_LISEN  
https://github.com/halfroad/TWAIMessager   
  
A great video showing how to use the S3's built in USB (and separate UART) in different modes, CDC/OTG:  
https://www.youtube.com/watch?v=hJSBTFsOnoA
    
Recommended settings in the Arduino IDE for the S3:  
  
Arduino IDE settings for ESP32-S3-WROOM-1-N16R8  
  
# Install USB drivers (if necessary)

The USB chip on the 2.x boards is a CP2104 from Silicon Labs

You can find drivers for your PC here under downloads https://www.silabs.com/developers/usb-to-uart-bridge-vcp-drivers

# Setting up the Arduino IDE for ESP32 on Windows

Download and install the Arduino IDE development editor https://www.arduino.cc/en/software
  
Start the IDE and go to File > Preferences  
  


Click the symbol on the right side  
  


Add the line  
https://dl.espressif.com/dl/package_esp32_index.json  
  


Go to Tools > Board: xxx > Boards Manager...  
  


Enter "ESP32" in the search box and hit enter to search, then click and install the latest version  
  


Go to Tools > Board: xxx > ESP32 Arduino > and choose ESP32 Dev Module  
  


Go to Tools > Manage Libraries...
  

  
When you have decided what CAN library/libraries you want to use, search for and install these from here. But since it is often a bit tricky to search for CAN libraries since the word "can" is present in many many other libraries it is often easier to go directly to github and download the library you are after, unzip and place the contents in the Arduino library directory (which normally is found in the same directory as where you place your projects).

Most of the code examples on here needs these two libraries https://github.com/collin80/esp32_can and https://github.com/collin80/can_common (as stated within the example code ;-)  

To set the S3 version of the ESP32 into code download mode, hold the PROG button pressed while pressing the RESET button. Release the RESET button first then the PROG button.
  


# Setting up the Arduino IDE for ESP32 on other platforms

- [Download and install](https://www.arduino.cc/en/software) Arduino IDE or cli for your platform.
- [Download and install](https://docs.espressif.com/projects/esp-idf/en/latest/esp32/get-started/#installation-step-by-step) ESP32 prerequisites
- Follow the steps 1-5 on setting up the ESP32 environment.
- If you wish to compile and flash the ESP32 [blink](https://github.com/espressif/esp-idf/tree/451ce8a7ed486c6c6045189db57106ca7107abdb/examples/get-started/blink) example, do so by going to ~/esp/esp-idf, and do
- $ source export.sh 
- $ cd ~/esp/esp-idf/examples/blink
- $ idf.py build to compile
- $ idf.py -p (PORT) flash
- If you have a v2.1 board, change #define BLINK_GPIO CONFIG_BLINK_GPIO to: #define BLINK_GPIO 13
- recompile and reflash to get the blue LED blinking
- Choose what CAN library/libraries you want to use and download, for example clone [esp32_can](https://github.com/collin80/esp32_can) and [can_common](https://github.com/collin80/can_common) to your ~/Arduino/libraries directory.
- copy obd2.h to ~/Arduino/libraries/obd2/ 
- Install [ESP32 environment for Arduino](https://dronebotworkshop.com/esp32-intro/)
- Choose "ESP32 Dev Module" as your board, build and flash!

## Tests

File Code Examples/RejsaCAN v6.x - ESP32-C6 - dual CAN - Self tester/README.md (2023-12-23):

# Example how to use both two CAN bus ports on an ESP32-C6

In this example:  
- CAN0 acts like an external OBD2 device requesting OBD2 rpm data from a car
- CAN1 acts like a car replying to OBD2 requests with dummy data
  
You can test either of the two CAN buses separately, CAN0 connected to a car or CAN1 connected to some external OBD2 device. Or connect the two buses together so CAN0 get replies from CAN1.  
  
If you do a self test with a short cable as the CAN bus between two transceivers don't forget to have 120ohm termination resistors activated (on a RejsaCAN they are activated/connected by default unless you cut the pcb trace)

## ESP-IDF Toolchain
You need espressif's 5.2 toolchain or newer since that has the twai v2 update (twai_driver_install_v2, twai_start_v2, twai_transmit_v2, twai_receive_v2 and so on) which supports multiple CAN controllers. Today (dec 2023) the only way to do this is via ESP-IDF with for example VSCode. Not PlatformIO's built in espressif toolchain since it seems to be an older version (I might be wrong but I couldn't get it to compile with PIO's built in ESP-IDF, if you find out how please tell me :-)  

##  
self test  
  
self test rear
  
292323542-6e29e880-1655-4fed-8590-ffe28d65e589
  
screw terminal 4

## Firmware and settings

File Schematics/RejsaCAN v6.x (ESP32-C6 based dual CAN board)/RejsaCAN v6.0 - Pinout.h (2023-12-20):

// Pinout v6.0



// Shortlist of all GPIO accessible on pin header / solder pads
#define GPIO1   1     // no default use
#define GPIO4   4     // SPI bus MTMS/CS SD_CARD.   Used by SD card slot. Free to use for anything if SD card slot isn't used
#define GPIO5   5     // Shared SPI bus MTDI/MISO.  Used by SD card slot. Free to use for anything if SD card slot isn't used
#define GPIO6   6     // Shared SPI bus MTCK/CLOCK. Used by SD card slot. Free to use for anything if SD card slot isn't used 
#define GPIO7   7     // Shared SPI bus MTDO/MOSI.  Used by SD card slot. Free to use for anything if SD card slot isn't used 
#define GPIO14  14    // no default use
#define GPIO15  15    // no default use
#define GPIO16  16    // Serial TXD or free to use for anything if serial port isn't used
#define GPIO17  17    // Serial RXD or free to use for anything if serial port isn't used



// GPIO for CAN
#define CAN0_RX       23
#define CAN0_TX       3
#define CAN1_RX       20
#define CAN1_TX       21


// OUTPUT HIGH = CAN low power mode (listen only)
// OUTPUT LOW = CAN high speed mode
// High impedance (INPUT) = CAN slope control mode
#define CAN0_RS       2
#define CAN1_RS       22  


// GPIO for extra serial port
#define SERIAL_TXD    16
#define SERIAL_RXD    17


// GPIO for SPI bus (shared with SD card slot)
#define MTDI          5
#define MTCK          6
#define MTDO          7
#define SD_CARD       4


// GPIO for other on board hardware
#define FORCE_ON      18   // Set high to keep board running even when the power voltage drops below 13.5V when the engine isn't running/charging battery
#define SENSE_V_ANA   0    // For measuring the incoming power voltage (detect discharge level, health of battery, if engine is running or not....)
#define POWER_LED     19   // To lower power consumption when in sleep set to OUTPUT LOW to turn off and *disable* the power led. Or control the green power LED on/off while board is running
#define RGB_LED       8    // WS2812C LED
#define BOOT_BUTTON   9    // Can be used *after* boot as a universal button

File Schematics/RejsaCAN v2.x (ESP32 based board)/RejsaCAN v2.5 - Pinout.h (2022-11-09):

// Pinout v2.4

#define FORCE_ON    25
#define SENSE_V_DIG 14
#define SENSE_V_ANA 35

#define BLUE_LED    13
#define YELLOW_LED  12

#define CAN_RX      16
#define CAN_TX      17
#define CAN_WAKEUP	4

#define HI_DRIVER   27    // 3V3 high driver power output

#define SDA         21    // I2C 
#define SCL         22    // I2C

#define SPI_MISO    19    // SPI
#define SPI_MOSI    23    // SPI
#define SPI_CLK     18    // SPI
#define SPI_SS      5     // SPI chip select for SD card reader or other off board auxiliaries 

#define KLINE_RX	34
#define KLINE_TX	32

/*
Also available on the row of pads:

GPIO33  General GPIO, no default use
GPIO26  General GPIO, no default use

*/





/*

Total list of available solderable breakout pads are:

GPIO21  or I2C SDA
GPIO22  or I2C SCL

GPIO18  or SPI CLK
GPIO23  or SPI MOSI
GPIO19  or SPI MISO
GPIO5   or SPI SS

GPIO33  General GPIO, no default use
GPIO26  General GPIO, no default use
GPIO27  Power output driver, not actual GPIO pin

GPIO12  LED only, no pad!
GPIO13  LED only, no pad!


*/

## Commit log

2021-10-27 Create board v2.0.ino
2021-10-27 Create board v2.1.ino
2021-11-08 Update board v2.1.ino
2021-12-24 Create board v2.2.ino
2021-12-24 Update board v2.2.ino
2022-06-21 pics of ESP32-S3 board
2022-07-21 link to schematics
2022-08-14 added link to USB drivers
2022-10-11 Update BOM_RejsaCAN v3.2.csv
    [BOM_RejsaCAN v3.2.csv]
2022-10-11 Update BOM_RejsaCAN v2.4.csv
    [BOM_RejsaCAN v2.4.csv]
2022-10-27 Create Auxiliary boards
2022-12-31 New casing with pcb connect board
2023-03-21 added serial print
2023-05-16 Added KiCad Symbol
2023-05-16 Updated Pin numbers in Symbol
2023-05-29 Link to great video on S3 USB/UART
2023-05-29 point to newer v3.4 schematic
2023-09-16 New version with S3 support
    New updated version with support for both S3 and non S3 ESP32
    Bluetooth removed, only prints over USB
2023-09-16 New version with S3 support
    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
2023-09-16 New version for all v3.x boards
2023-09-26 renamed housings
2023-11-13 Added link to ESP32S3RET
2023-11-21 Add files via upload
    ESP32-C6 based which adds dual CAN and Zigbee
2023-12-24 added rgb led
2023-12-25 Added voltage table
2024-01-01 Uploaded new schematics
    [BOM_RejsaCAN v2.4.csv, BOM_Rejsa_CAN v3.4.csv, RejsaCAN v2.5 - BOM.csv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]
2024-01-02 Add Gerbers
2024-01-08 Create RejsaCAN v6.0 - BOM.csv
    [RejsaCAN v6.0 - BOM.csv]
2025-08-02 sub directories in Schematics
    [RejsaCAN v2.5 - BOM.csv, RejsaCAN v3.4 - BOM.csv, RejsaCAN v6.0 - BOM.csv]
